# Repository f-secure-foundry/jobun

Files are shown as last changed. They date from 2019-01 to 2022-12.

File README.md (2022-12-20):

Introduction
============

jobun | https://github.com/f-secure-foundry/jobun  
Copyright (c) F-Secure Corporation

The jobun (序文) board implements a platform for transmission of truly
arbitrary Ethernet (802.3u - 100BASE-FX, 100BASETX and 10BASE-Te) packets, by
means of an FPGA based software Media Access Control (MAC) connected to a
physical (PHY) Ethernet transceiver.

The FPGA is a Lattice Semiconductor MachXO2 (P/N LCMXO2-1200HC-4SG32C), the
Ethernet transceiver is a Texas Instruments DP83822.

The PCB features a design that allows to use the FPGA side of the board
independently of the Ethernet PHY one. A 2.54mm 20x2 pin header must be
soldered to interconnect the two sides through connection shunts (jumpers).

With some courage, the two sides can also be snapped off each other for fully
independent use.

The board features a USB micro-AB receptacle for programming and operation.

The jobun design has been initially designed to provide a platform for the
Start-of-Frame delimiter (SFD) manipulation attacks described in the following
research:

* A. Barisani and D. Bianco
  “Fully Arbitrary 802.3 Packet Injection: Maximizing the Ethernet Attack Surface”  
  [Link](https://github.com/abarisani/abarisani.github.io/tree/master/research/802.3)

jobun board

Authors
=======

Andrea Barisani  
andrea@inversepath.com  

Andrej Rosano  
andrej@inversepath.com  

Firmware
========

The on-board MachXO2 FPGA can be programmed, over USB, by placing a jumper on
the JP1 connector located on the upper left corner. The jumper must be then
removed and the board restarted to allow Ethernet PHY reconfiguration and
firmware startup.

The `firmware` directory contains a Lattice Diamond project file for a basic
packet transmission tool named file2cable to honour FX's homonym tool, part of
the legendary IRPAS from Phenoelit.

While the original IRPAS file2cable tool can be used to transmit a "MAC Frame",
jobun can send a "MAC Packet" (see paper linked earlier), therefore achieving
better coverage ;) in transmitting an actual file to the cable. The file in
question is `firmware/mac_pkt.txt`.

This [wiki](https://wiki.archlinux.org/index.php/Lattice_Diamond) contains
useful information on how to get started with Lattice Diamond.

Revision information
====================

Current schematics and layout files have been designed in KiCad 5.0.1.

PCB information
===============

2 layers, 1.60mm thickness, top only components  
Outer layers 0.5 oz base copper foil  
Inner layers   1 oz base copper foil  
width (X) 55.1 mm, height (Y) 50.5 mm  
Blue soldermask, white component legend

DRC information
---------------

Minimum track width:            0.254 mm  
Minimum via diameter:           0.450 mm  
Outer layer track width:        0.139 mm  
Outer layer isolation distance: 0.127 mm  
Outer layer annular ring:       0.100 mm  
Smallest final hole (plated):   0.150 mm

License
=======

Copyright (c) F-Secure Corporation

This is an open hardware design licensed under the terms of the CERN Open
Hardware Licence (OHL) v1.2.

You may redistribute and modify this documentation under the terms of the CERN
OHL v.1.2 (http://ohwr.org/cernohl). This documentation is distributed WITHOUT
ANY EXPRESS OR IMPLIED WARRANTY, INCLUDING OF MERCHANTABILITY, SATISFACTORY
QUALITY AND FITNESS FOR A PARTICULAR PURPOSE. Please see the CERN OHL v.1.2 for
applicable conditions.

The following exceptions apply:

- `hardware/lib.snapeda`: all files in this directory are imported or modified
  from SnapEDA symbols and footprints, therefore the license at
  https://www.snapeda.com/about/FAQ/#license applies.

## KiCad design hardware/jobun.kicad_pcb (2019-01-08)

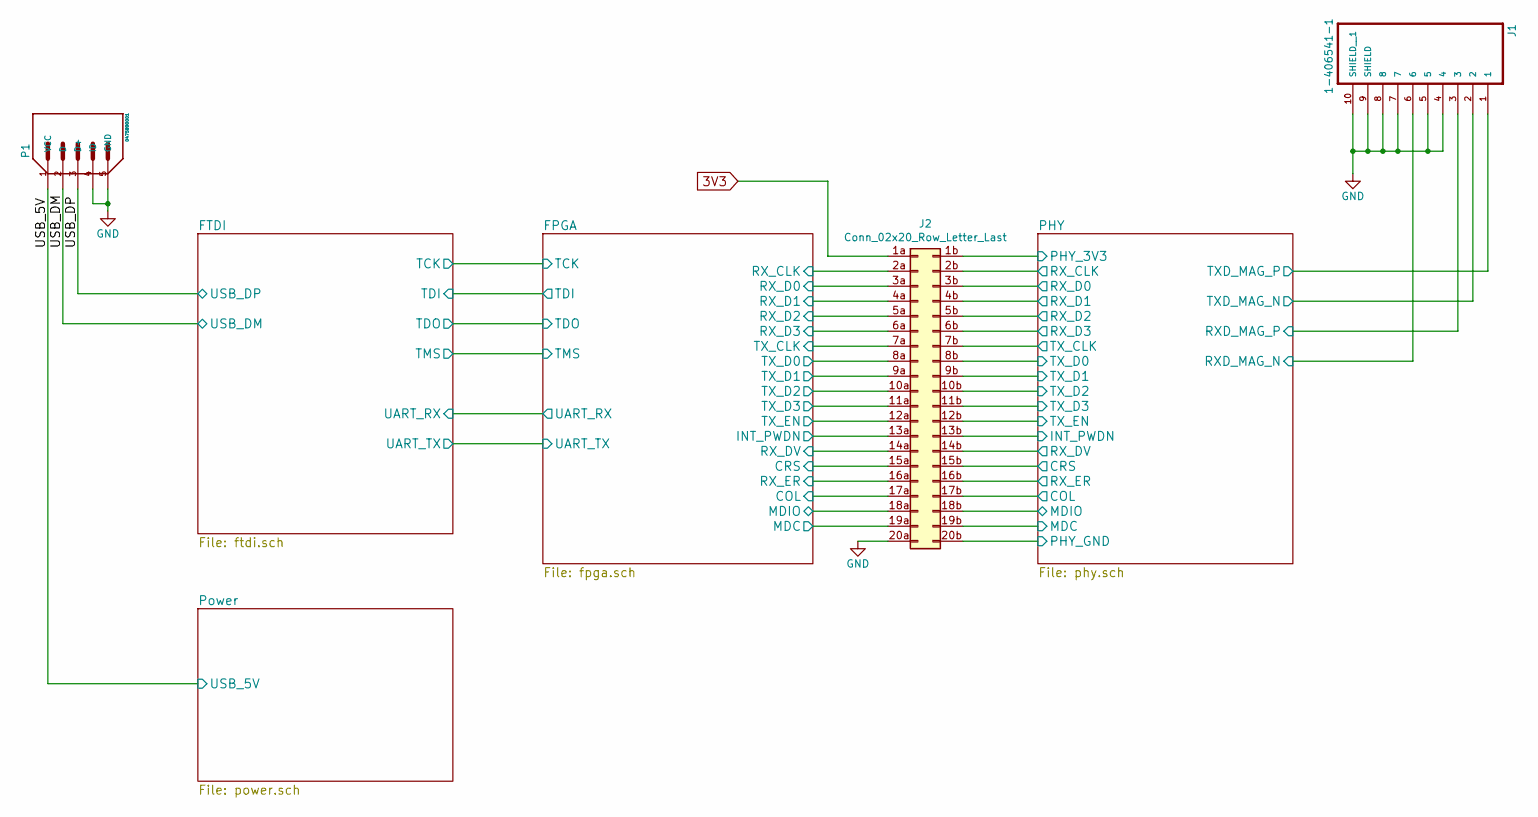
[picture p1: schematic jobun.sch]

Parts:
J1: 1-406541-1; CONN_1-406541-1; Mfg PN 1-406541-1
J2: Conn_02x20_Row_Letter_Last; jobun_pcb_mezzanine-20X2
P1: 0475890001; MOLEX_0475890001; Mfg PN 0475890001

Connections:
3V3: J2.1a; also elsewhere on the board
/FPGA/COL: J2.17a; also elsewhere on the board
/FPGA/CRS: J2.15a; also elsewhere on the board
/FPGA/INT_PWDN: J2.13a; also elsewhere on the board
/FPGA/MDC: J2.19a; also elsewhere on the board
/FPGA/MDIO: J2.18a; also elsewhere on the board
/FPGA/RX_CLK: J2.2a; also elsewhere on the board
/FPGA/RX_D0: J2.3a; also elsewhere on the board
/FPGA/RX_D1: J2.4a; also elsewhere on the board
/FPGA/RX_D2: J2.5a; also elsewhere on the board
/FPGA/RX_D3: J2.6a; also elsewhere on the board
/FPGA/RX_DV: J2.14a; also elsewhere on the board
/FPGA/RX_ER: J2.16a; also elsewhere on the board
/FPGA/TX_CLK: J2.7a; also elsewhere on the board
/FPGA/TX_D0: J2.8a; also elsewhere on the board
/FPGA/TX_D1: J2.9a; also elsewhere on the board
/FPGA/TX_D2: J2.10a; also elsewhere on the board
/FPGA/TX_D3: J2.11a; also elsewhere on the board
/FPGA/TX_EN: J2.12a; also elsewhere on the board
/PHY/COL: J2.17b; also elsewhere on the board
/PHY/CRS: J2.15b; also elsewhere on the board
/PHY/INT_PWDN: J2.13b; also elsewhere on the board
/PHY/MDC: J2.19b; also elsewhere on the board
/PHY/MDIO: J2.18b; also elsewhere on the board
/PHY/PHY_3V3: J2.1b; also elsewhere on the board
/PHY/RXD_MAG_N: J1.6; also elsewhere on the board
/PHY/RXD_MAG_P: J1.3; also elsewhere on the board
/PHY/RX_CLK: J2.2b; also elsewhere on the board
/PHY/RX_D0: J2.3b; also elsewhere on the board
/PHY/RX_D1: J2.4b; also elsewhere on the board
/PHY/RX_D2: J2.5b; also elsewhere on the board
/PHY/RX_D3: J2.6b; also elsewhere on the board
/PHY/RX_DV: J2.14b; also elsewhere on the board
/PHY/RX_ER: J2.16b; also elsewhere on the board
/PHY/TXD_MAG_N: J1.2; also elsewhere on the board
/PHY/TXD_MAG_P: J1.1; also elsewhere on the board
/PHY/TX_CLK: J2.7b; also elsewhere on the board
/PHY/TX_D0: J2.8b; also elsewhere on the board
/PHY/TX_D1: J2.9b; also elsewhere on the board
/PHY/TX_D2: J2.10b; also elsewhere on the board
/PHY/TX_D3: J2.11b; also elsewhere on the board
/PHY/TX_EN: J2.12b; also elsewhere on the board
/USB_5V: P1.1 (VCC); also elsewhere on the board
/USB_DM: P1.2 (D); also elsewhere on the board
/USB_DP: P1.3 (D+); also elsewhere on the board
GND: J1.4, J1.5, J1.7, J1.8, J1.9 (SHIELD), J1.10 (SHIELD__1), J2.20a, J2.20b, P1.4 (ID), P1.5 (GND); also elsewhere on the board

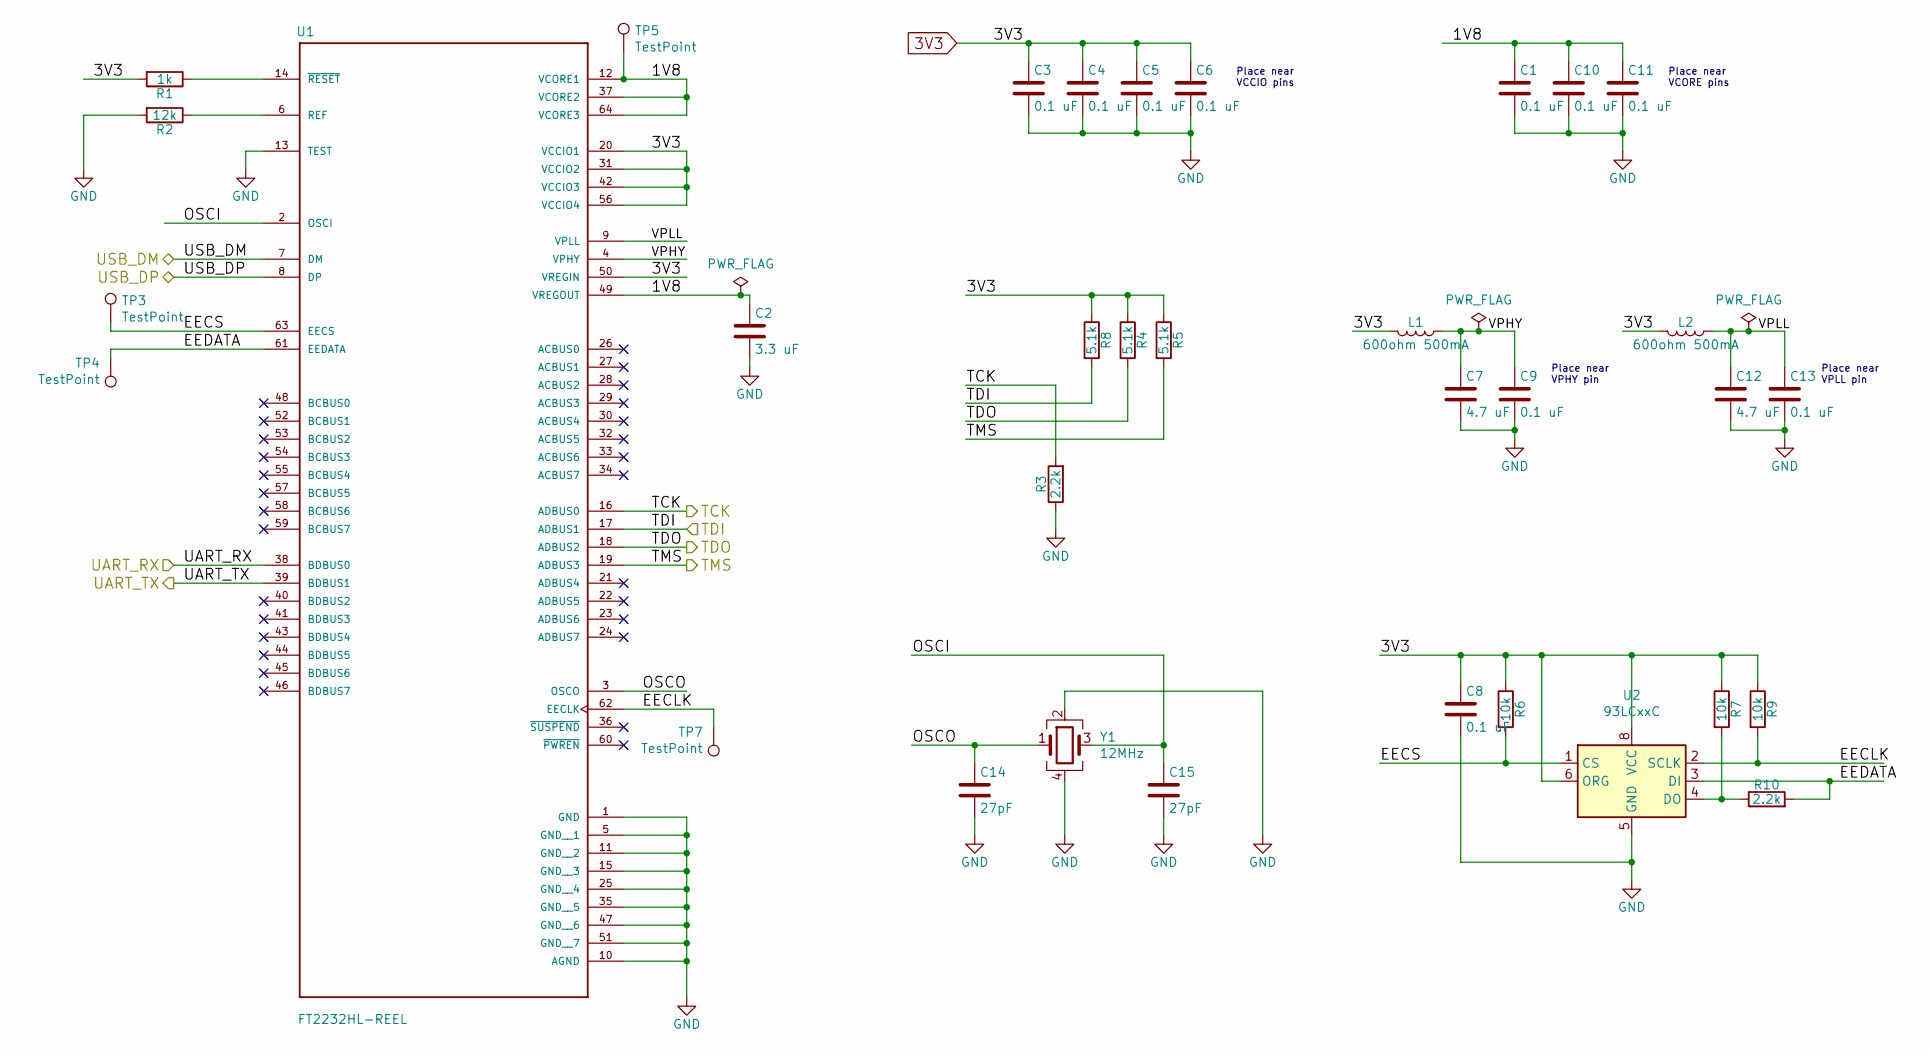
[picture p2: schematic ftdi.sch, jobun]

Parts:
C1, C3, C4, C5, C6, C8, C9, C10, C11, C13: 0.1 uF; SM0603; Mfg PN C1608X7R1E104K080AA
C2: 3.3 uF; SM0603; Mfg PN C1608X5R1C335K080AC
C7, C12: 4.7 uF; SM0603; Mfg PN CGB3B1X5R1A475M055AC
C14, C15: 27pF; SM0603; Mfg PN GRM1885C1H270FA01D
L1, L2: 600ohm 500mA; SM0603; Mfg PN BLM18AG601SN1D
R1: 1k; SM0603; Mfg PN RCA06031K00FKEAHP
R2: 12k; SM0603; Mfg PN CRCW060312K0FKEAC
R3, R10: 2.2k; SM0603; Mfg PN RCS06032K20JNEA
R4, R5, R8: 5.1k; SM0603; Mfg PN CRCW06035K10FKEAC
R6, R7, R9: 10k; SM0603; Mfg PN CRCW060310K0FKEA
TP3, TP4, TP5, TP7: TestPoint; TP
U1: FT2232HL-REEL; QFP50P1200X1200X160-64N; Mfg PN FT2232HL-REEL
U2: 93LCxxC; 8L_SOIC_Narrow_3_90_SN_C04-057C; Mfg PN 93LC56C-I/SN
Y1: 12MHz; TXC-3.2x2.5; Mfg PN 7M-12.000MAAJ-T

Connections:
3V3: C3.1, C4.1, C5.1, C6.1, C8.1, L1.1, L2.1, R1.2, R4.1, R5.1, R6.1, R7.1, R8.1, R9.1, U1.20 (VCCIO1), U1.31 (VCCIO2), U1.42 (VCCIO3), U1.50 (VREGIN), U1.56 (VCCIO4), U2.6 (ORG), U2.8 (VCC); also elsewhere on the board
/FPGA/TCK: R3.2, U1.16 (ADBUS0); also elsewhere on the board
/FPGA/TDI: R8.2, U1.17 (ADBUS1); also elsewhere on the board
/FPGA/TDO: R4.2, U1.18 (ADBUS2); also elsewhere on the board
/FPGA/TMS: R5.2, U1.19 (ADBUS3); also elsewhere on the board
/FPGA/UART_RX: U1.38 (BDBUS0); also elsewhere on the board
/FPGA/UART_TX: U1.39 (BDBUS1); also elsewhere on the board
/FTDI/1V8: C1.1, C2.1, C10.1, C11.1, TP5.1, U1.12 (VCORE1), U1.37 (VCORE2), U1.49 (VREGOUT), U1.64 (VCORE3)
/FTDI/EECLK: R9.2, TP7.1, U1.62 (EECLK), U2.2 (SCLK)
/FTDI/EECS: R6.2, TP3.1, U1.63 (EECS), U2.1 (CS)
/FTDI/EEDATA: R10.2, TP4.1, U1.61 (EEDATA), U2.3 (DI)
/FTDI/OSCI: C15.1, U1.2 (OSCI), Y1.3
/FTDI/OSCO: C14.1, U1.3 (OSCO), Y1.1
/FTDI/VPHY: C7.1, C9.1, L1.2, U1.4 (VPHY)
/FTDI/VPLL: C12.1, C13.1, L2.2, U1.9 (VPLL)
/USB_DM: U1.7 (DM); also elsewhere on the board
/USB_DP: U1.8 (DP); also elsewhere on the board
GND: C1.2, C2.2, C3.2, C4.2, C5.2, C6.2, C7.2, C8.2, C9.2, C10.2, C11.2, C12.2, C13.2, C14.2, C15.2, R2.2, R3.1, U1.1 (GND), U1.5 (GND__1), U1.10 (AGND), U1.11 (GND__2), U1.13 (TEST), U1.15 (GND__3), U1.25 (GND__4), U1.35 (GND__5), U1.47 (GND__6), U1.51 (GND__7), U2.5 (GND), Y1.2, Y1.4; also elsewhere on the board
unnamed: R1.1, U1.14 (~RESET~)
unnamed: R2.1, U1.6 (REF)
unnamed: R7.2, R10.1, U2.4 (DO)

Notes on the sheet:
Place near VCORE pins
Place near VCCIO pins
Place near VPLL pin
Place near VPHY pin

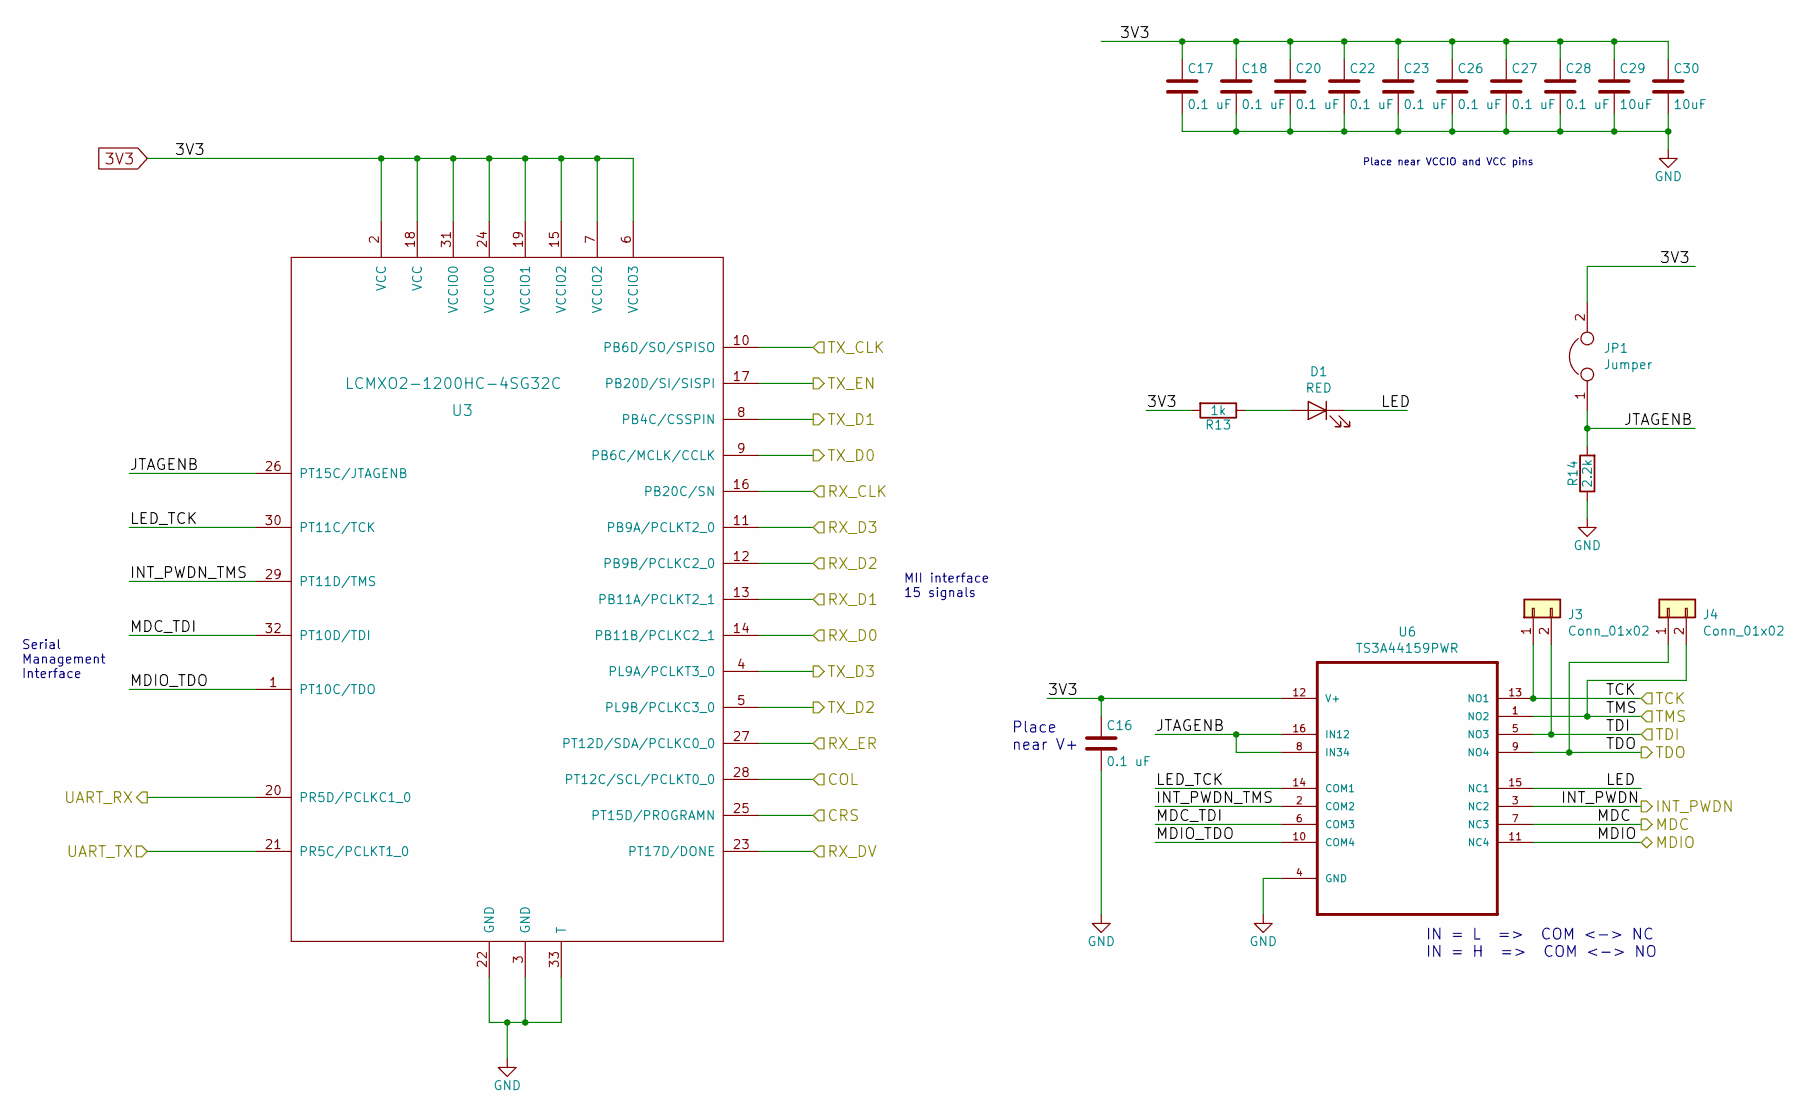
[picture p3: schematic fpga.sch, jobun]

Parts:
C16, C17, C18, C20, C22, C23, C26, C27, C28: 0.1 uF; SM0603; Mfg PN C1608X7R1E104K080AA
C29, C30: 10uF; SM0603; Mfg PN C1608X5R1A106M080AC
D1: RED; SM0603; Mfg PN LTST-C190KRKT
J3, J4: Conn_01x02; pinhead-1X2
JP1: Jumper; pinhead-1X2
R13: 1k; SM0603; Mfg PN RCA06031K00FKEAHP
R14: 2.2k; SM0603; Mfg PN RCS06032K20JNEA
U3: LCMXO2-1200HC-4SG32C; SG32C; Mfg PN LCMXO2-1200HC-4SG32C
U6: TS3A44159PWR; Mfg PN TS3A44159PWR

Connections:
3V3: C16.1, C17.1, C18.1, C20.1, C22.1, C23.1, C26.1, C27.1, C28.1, C29.1, C30.1, JP1.2, R13.2, U3.2 (VCC), U3.6 (VCCIO3), U3.7 (VCCIO2), U3.15 (VCCIO2), U3.18 (VCC), U3.19 (VCCIO1), U3.24 (VCCIO0), U3.31 (VCCIO0), U6.12 (V+); also elsewhere on the board
/FPGA/COL: U3.28 (PT12C/SCL/PCLKT0_0); also elsewhere on the board
/FPGA/CRS: U3.25 (PT15D/PROGRAMN); also elsewhere on the board
/FPGA/INT_PWDN: U6.3 (NC2); also elsewhere on the board
/FPGA/INT_PWDN_TMS: U3.29 (PT11D/TMS), U6.2 (COM2)
/FPGA/JTAGENB: JP1.1, R14.2, U3.26 (PT15C/JTAGENB), U6.8 (IN34), U6.16 (IN12)
/FPGA/LED: D1.1 (K), U6.15 (NC1)
/FPGA/LED_TCK: U3.30 (PT11C/TCK), U6.14 (COM1)
/FPGA/MDC: U6.7 (NC3); also elsewhere on the board
/FPGA/MDC_TDI: U3.32 (PT10D/TDI), U6.6 (COM3)
/FPGA/MDIO: U6.11 (NC4); also elsewhere on the board
/FPGA/MDIO_TDO: U3.1 (PT10C/TDO), U6.10 (COM4)
/FPGA/RX_CLK: U3.16 (PB20C/SN); also elsewhere on the board
/FPGA/RX_D0: U3.14 (PB11B/PCLKC2_1); also elsewhere on the board
/FPGA/RX_D1: U3.13 (PB11A/PCLKT2_1); also elsewhere on the board
/FPGA/RX_D2: U3.12 (PB9B/PCLKC2_0); also elsewhere on the board
/FPGA/RX_D3: U3.11 (PB9A/PCLKT2_0); also elsewhere on the board
/FPGA/RX_DV: U3.23 (PT17D/DONE); also elsewhere on the board
/FPGA/RX_ER: U3.27 (PT12D/SDA/PCLKC0_0); also elsewhere on the board
/FPGA/TCK: J3.1, U6.13 (NO1); also elsewhere on the board
/FPGA/TDI: J3.2, U6.5 (NO3); also elsewhere on the board
/FPGA/TDO: J4.1, U6.9 (NO4); also elsewhere on the board
/FPGA/TMS: J4.2, U6.1 (NO2); also elsewhere on the board
/FPGA/TX_CLK: U3.10 (PB6D/SO/SPISO); also elsewhere on the board
/FPGA/TX_D0: U3.9 (PB6C/MCLK/CCLK); also elsewhere on the board
/FPGA/TX_D1: U3.8 (PB4C/CSSPIN); also elsewhere on the board
/FPGA/TX_D2: U3.5 (PL9B/PCLKC3_0); also elsewhere on the board
/FPGA/TX_D3: U3.4 (PL9A/PCLKT3_0); also elsewhere on the board
/FPGA/TX_EN: U3.17 (PB20D/SI/SISPI); also elsewhere on the board
/FPGA/UART_RX: U3.20 (PR5D/PCLKC1_0); also elsewhere on the board
/FPGA/UART_TX: U3.21 (PR5C/PCLKT1_0); also elsewhere on the board
GND: C16.2, C17.2, C18.2, C20.2, C22.2, C23.2, C26.2, C27.2, C28.2, C29.2, C30.2, R14.1, U3.3 (GND), U3.22 (GND), U3.33 (T), U6.4 (GND); also elsewhere on the board
unnamed: D1.2 (A), R13.1

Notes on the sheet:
Place near VCCIO and VCC pins
MII interface 15 signals
Serial Management Interface
IN = L => COM <-> NC IN = H => COM <-> NO
Place near V+

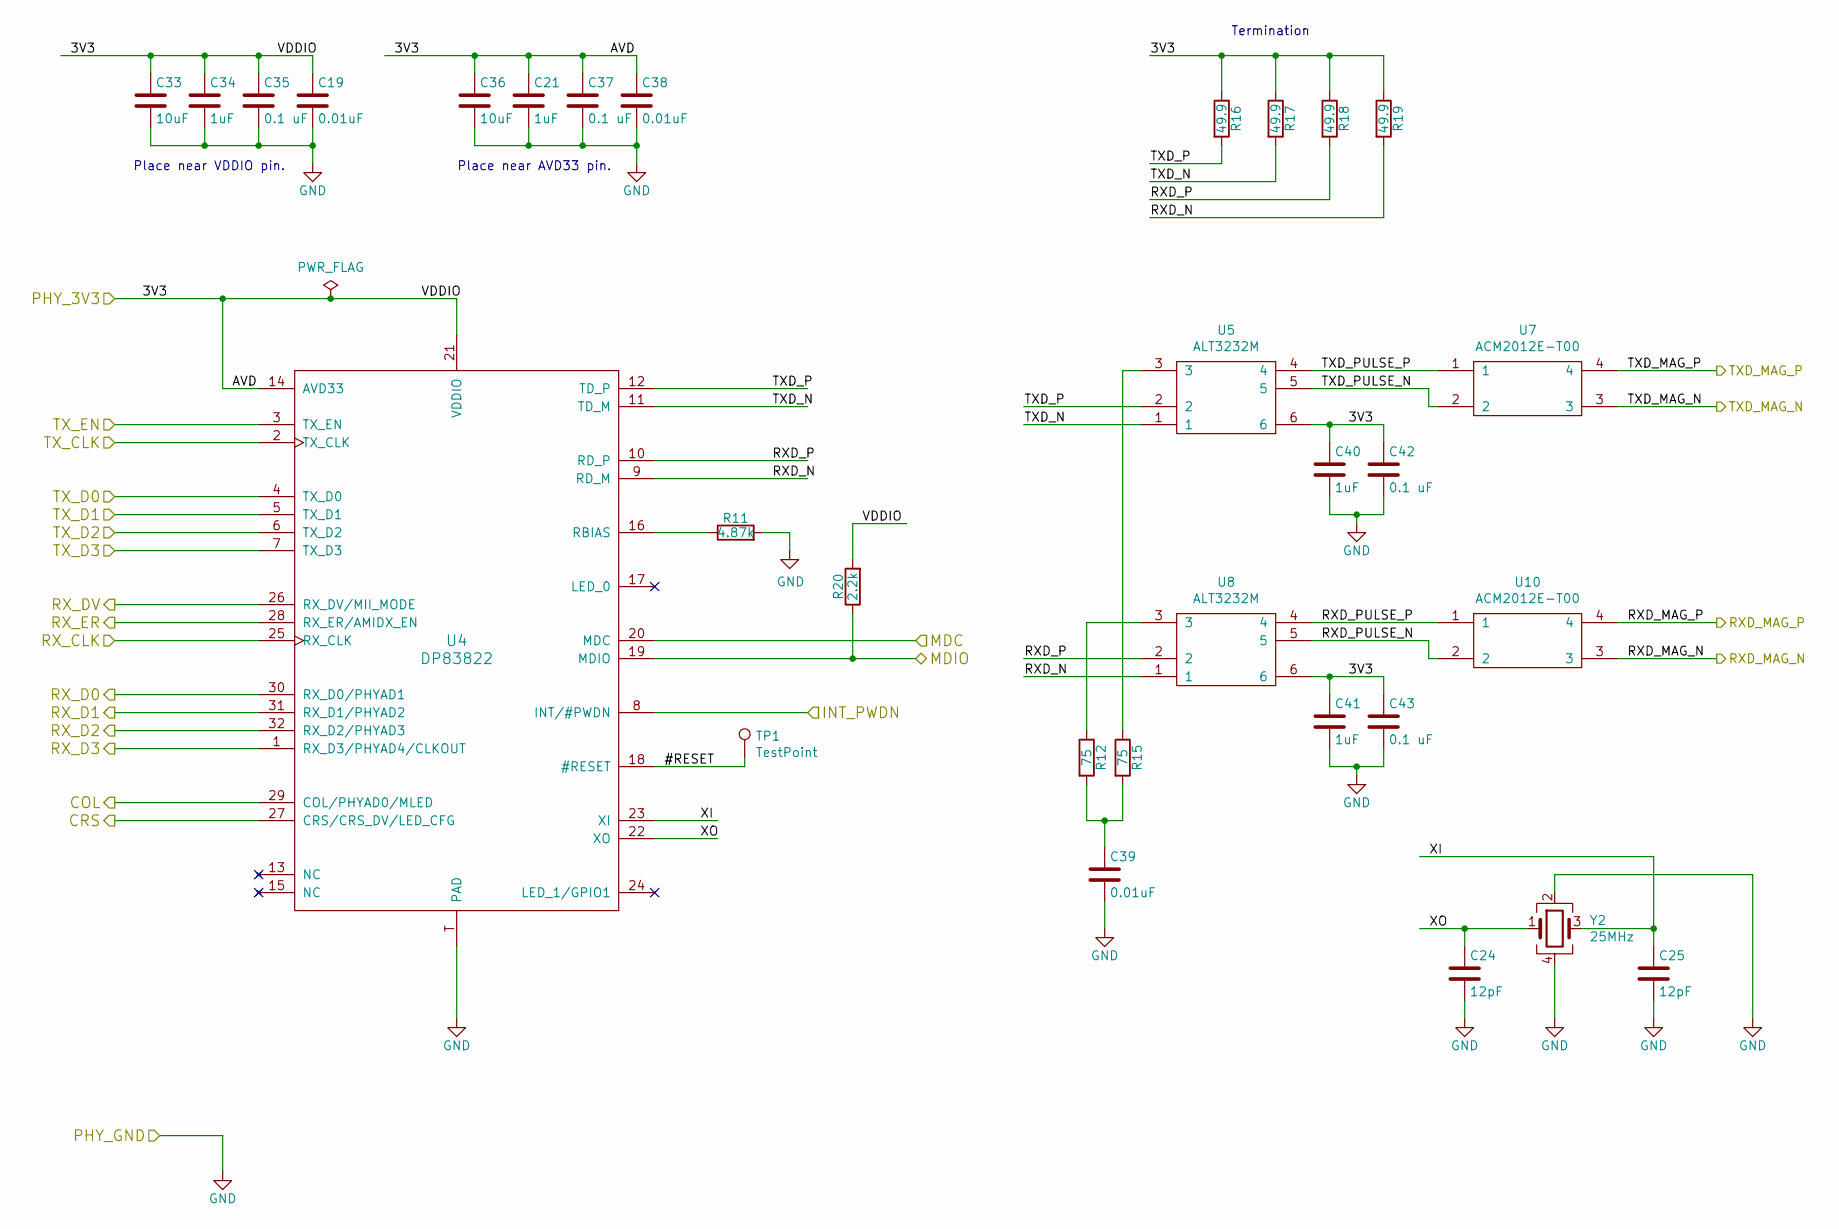
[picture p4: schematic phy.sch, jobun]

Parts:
C19, C38, C39: 0.01uF; SM0603; Mfg PN CGA3E2X7R2A103K080AA
C21, C34, C40, C41: 1uF; SM0603; Mfg PN CGA3E1X7R1C105M080AC
C24, C25: 12pF; SM0603; Mfg PN C1608NP02A120J080AA
C33, C36: 10uF; SM0603; Mfg PN C1608X5R1A106M080AC
C35, C37, C42, C43: 0.1 uF; SM0603; Mfg PN C1608X7R1E104K080AA
R11: 4.87k; SM0603; Mfg PN CRCW06034K87FKEA
R12, R15: 75; SM0603; Mfg PN RCS060375R0FKEA
R16, R17, R18, R19: 49.9; SM0603; Mfg PN CRCW060349R9FKEAHP
R20: 2.2k; SM0603; Mfg PN RCS06032K20JNEA
TP1: TestPoint; TP
U4: DP83822; VQFN-32; Mfg PN DP83822IFRHBT
U5, U8: ALT3232M; Mfg PN ALT3232M-151-T001
U7, U10: ACM2012E-T00; Mfg PN ACM2012E-900-2P-T00
Y2: 25MHz; OSCCC250X320X70-4N; Mfg PN ABM8AIG-25.000MHZ-12-2Z-T3

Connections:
/PHY/#RESET: TP1.1, U4.18 (#RESET)
/PHY/COL: U4.29 (COL/PHYAD0/MLED); also elsewhere on the board
/PHY/CRS: U4.27 (CRS/CRS_DV/LED_CFG); also elsewhere on the board
/PHY/INT_PWDN: U4.8 (INT/#PWDN); also elsewhere on the board
/PHY/MDC: U4.20 (MDC); also elsewhere on the board
/PHY/MDIO: R20.1, U4.19 (MDIO); also elsewhere on the board
/PHY/PHY_3V3: C19.1, C21.1, C33.1, C34.1, C35.1, C36.1, C37.1, C38.1, C40.1, C41.1, C42.1, C43.1, R16.1, R17.1, R18.1, R19.1, R20.2, U4.14 (AVD33), U4.21 (VDDIO), U5.6, U8.6; also elsewhere on the board
/PHY/RXD_MAG_N: U10.3; also elsewhere on the board
/PHY/RXD_MAG_P: U10.4; also elsewhere on the board
/PHY/RXD_N: R19.2, U4.9 (RD_M), U8.1
/PHY/RXD_P: R18.2, U4.10 (RD_P), U8.2
/PHY/RXD_PULSE_N: U8.5, U10.2
/PHY/RXD_PULSE_P: U8.4, U10.1
/PHY/RX_CLK: U4.25 (RX_CLK); also elsewhere on the board
/PHY/RX_D0: U4.30 (RX_D0/PHYAD1); also elsewhere on the board
/PHY/RX_D1: U4.31 (RX_D1/PHYAD2); also elsewhere on the board
/PHY/RX_D2: U4.32 (RX_D2/PHYAD3); also elsewhere on the board
/PHY/RX_D3: U4.1 (RX_D3/PHYAD4/CLKOUT); also elsewhere on the board
/PHY/RX_DV: U4.26 (RX_DV/MII_MODE); also elsewhere on the board
/PHY/RX_ER: U4.28 (RX_ER/AMIDX_EN); also elsewhere on the board
/PHY/TXD_MAG_N: U7.3; also elsewhere on the board
/PHY/TXD_MAG_P: U7.4; also elsewhere on the board
/PHY/TXD_N: R17.2, U4.11 (TD_M), U5.1
/PHY/TXD_P: R16.2, U4.12 (TD_P), U5.2
/PHY/TXD_PULSE_N: U5.5, U7.2
/PHY/TXD_PULSE_P: U5.4, U7.1
/PHY/TX_CLK: U4.2 (TX_CLK); also elsewhere on the board
/PHY/TX_D0: U4.4 (TX_D0); also elsewhere on the board
/PHY/TX_D1: U4.5 (TX_D1); also elsewhere on the board
/PHY/TX_D2: U4.6 (TX_D2); also elsewhere on the board
/PHY/TX_D3: U4.7 (TX_D3); also elsewhere on the board
/PHY/TX_EN: U4.3 (TX_EN); also elsewhere on the board
/PHY/XI: C25.1, U4.23 (XI), Y2.3
/PHY/XO: C24.1, U4.22 (XO), Y2.1
GND: C19.2, C21.2, C24.2, C25.2, C33.2, C34.2, C35.2, C36.2, C37.2, C38.2, C39.2, C40.2, C41.2, C42.2, C43.2, R11.2, U4.T (PAD), Y2.2, Y2.4; also elsewhere on the board
unnamed: C39.1, R12.2, R15.2
unnamed: R11.1, U4.16 (RBIAS)
unnamed: R12.1, U8.3
unnamed: R15.1, U5.3

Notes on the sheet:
Termination
Place near AVD33 pin.
Place near VDDIO pin.

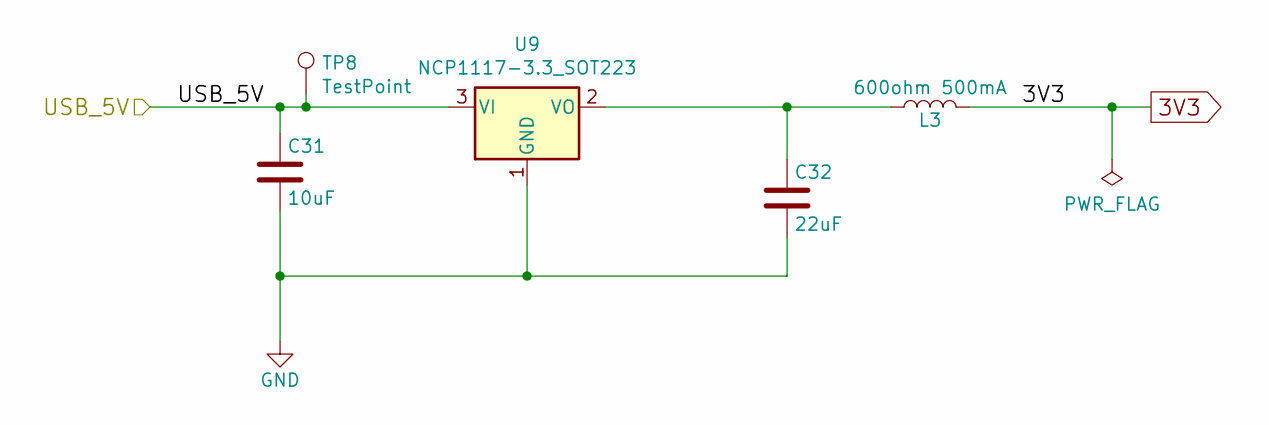
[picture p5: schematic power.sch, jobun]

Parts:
C31: 10uF; SM0603; Mfg PN C1608X5R1A106M080AC
C32: 22uF; SM0603; Mfg PN C1608X5R1A226M080AC
L3: 600ohm 500mA; SM0603; Mfg PN BLM18AG601SN1D
TP8: TestPoint; TP
U9: NCP1117-3.3_SOT223; SOT-223; Mfg PN NCP1117ST33T3G

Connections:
3V3: L3.2; also elsewhere on the board
/USB_5V: C31.1, TP8.1, U9.3 (VI); also elsewhere on the board
GND: C31.2, C32.2, U9.1 (GND); also elsewhere on the board
unnamed: C32.1, L3.1, U9.2 (VO)

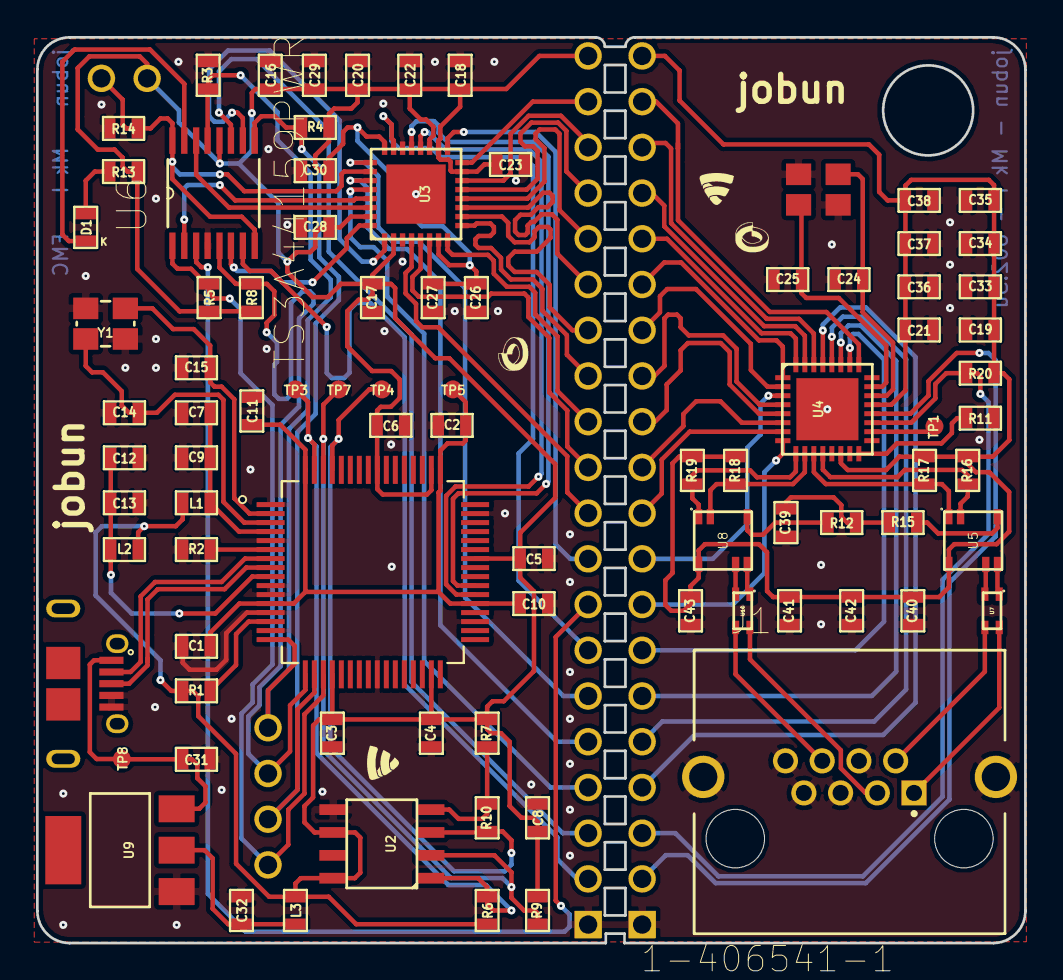
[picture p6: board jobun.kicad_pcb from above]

Board: 2 copper layers, 54.9 x 50.3 mm, 95 parts (0 on the bottom side), 86 nets.

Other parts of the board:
FSC_LOGO_NO_TEXT_SMALL: G***; FSC_LOGO_NO_TEXT_SMALL
FSC_LOGO_NO_TEXT_SMALL#2: G***; FSC_LOGO_NO_TEXT_SMALL
Ref**: Val**; IP_LOGO_NO_TEXT_SMALL
Ref**#2: Val**; IP_LOGO_NO_TEXT_SMALL

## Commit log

2019-01-08 initial import
    [fpga.sch, ftdi.sch, jobun.kicad_pcb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]
2019-01-08 link board image
2019-01-09 code cleanup and set minimum inter-frame gap value

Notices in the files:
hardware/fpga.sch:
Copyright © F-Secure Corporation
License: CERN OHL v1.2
